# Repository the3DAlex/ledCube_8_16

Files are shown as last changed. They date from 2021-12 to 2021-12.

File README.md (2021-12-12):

# ledCube_8_16
When cube will be ready install https://github.com/LuisMiCa/IRsmallDecoder in Arduino IDE.
From Example>IRsmallDecoder open HelloNEC example.
In the "IRsmallDecoder irDecoder(2);"  put your port number (in our case 10)
In "Serial.begin(250000);" put your terminal speed (Arduino Serial Monitor default value is 9600)
Burn sketch to cube.
Get your IR Pult and press all button one by one and remember it cmd.
Open LEDCube8_16.ino  and in loop void ander switch statement put thous cmd numbers. 
For example : "case 0x13:" where 0x13 - is yor cmd = button.
Note that not all pult works with this library. If no cmd shown - try another pult.

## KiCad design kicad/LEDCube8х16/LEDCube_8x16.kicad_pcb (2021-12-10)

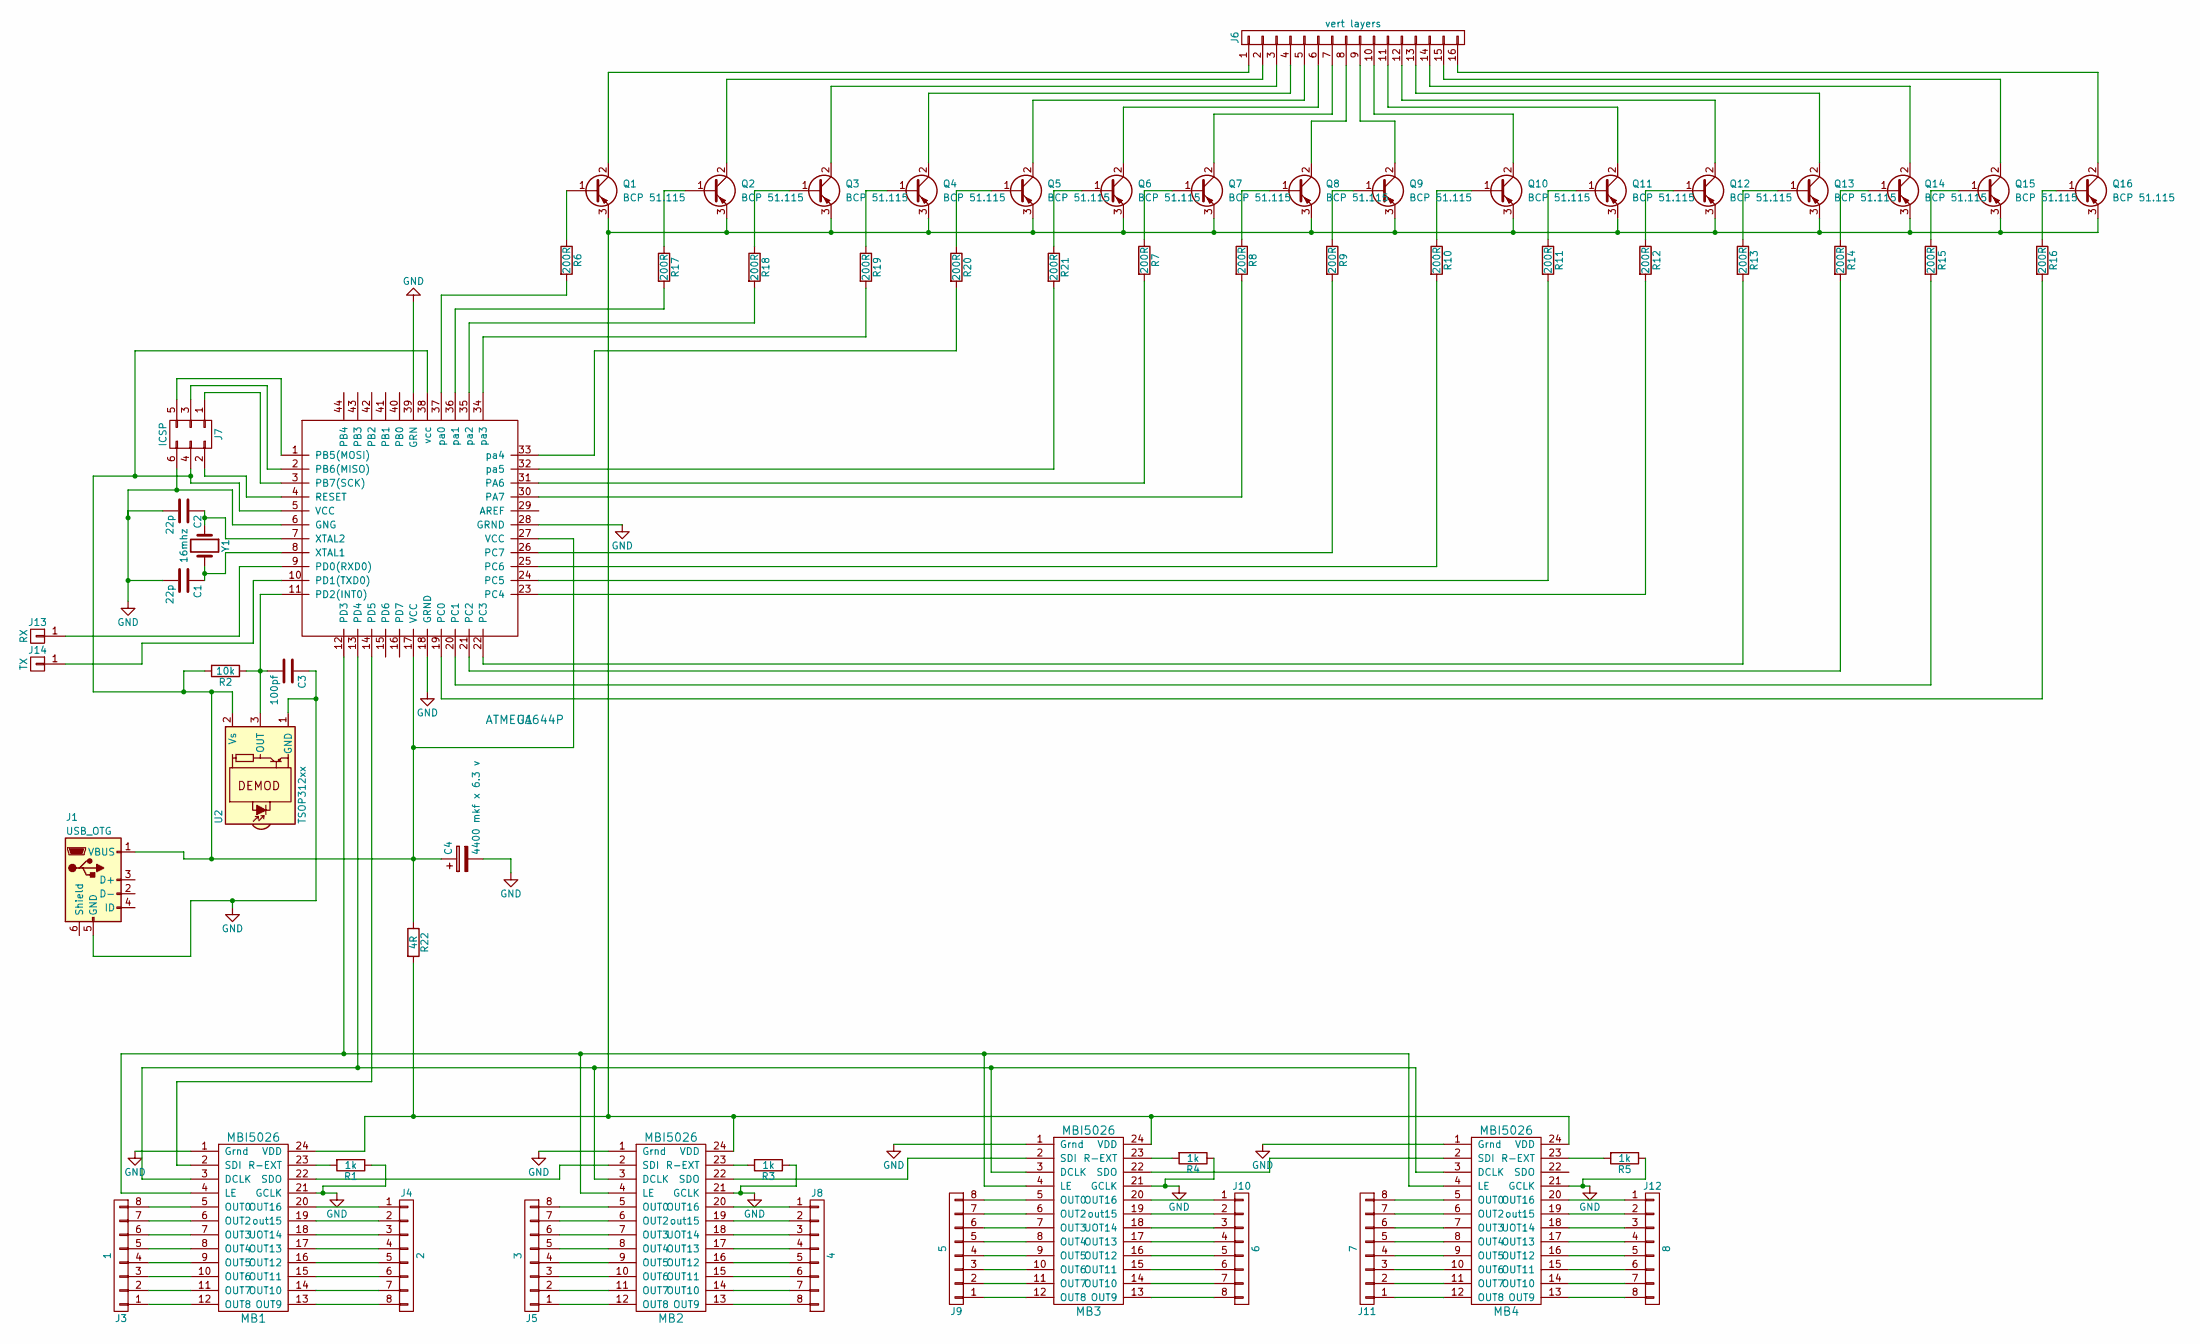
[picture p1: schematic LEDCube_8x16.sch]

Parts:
C1, C2: 22p; C_0805
C3: 100pf; C_0805
C4: 4400 mkf x 6.3 v; CP_Radial_D18.0mm_P7.50mm
J1: USB_OTG; USB_Micro-B
J3: 1; Pin_Header_Straight_1x08_Pitch1.00mm
J4: 2; Pin_Header_Straight_1x08_Pitch1.00mm
J5: 3; Pin_Header_Straight_1x08_Pitch1.00mm
J6: vert layers; Pin_Header_Straight_1x16_Pitch1.00mm
J7: ICSP; Pin_Header_Straight_2x03_Pitch2.54mm
J8: 4; Pin_Header_Straight_1x08_Pitch1.00mm
J9: 5; Pin_Header_Straight_1x08_Pitch1.00mm
J10: 6; Pin_Header_Straight_1x08_Pitch1.00mm
J11: 7; Pin_Header_Straight_1x08_Pitch1.00mm
J12: 8; Pin_Header_Straight_1x08_Pitch1.00mm
J13: RX; Pin_Header_Straight_1x01_Pitch2.54mm
J14: TX; Pin_Header_Straight_1x01_Pitch2.54mm
MB1, MB2, MB3, MB4: MBI5026; MBI5030
Q1, Q2, Q3, Q4, Q5, Q6, Q7, Q8, Q9, Q10, Q11, Q12, Q13, Q14, Q15, Q16: BCP 51.115; TO-92_Molded_Wide
R1, R3, R4, R5: 1k; R_0805
R2: 10k; R_0805
R6, R7, R8, R9, R10, R11, R12, R13, R14, R15, R16, R17, R18, R19, R20, R21: 200R; R_0805
R22: 4R; R_Axial_DIN0411_L9.9mm_D3.6mm_P7.62mm_Vertical
U1: ATMEGA644P; TQFP-44_10x10mm_Pitch0.8mm
U2: TSOP312xx; IRReceiver_Vishay_CAST-3pin
Y1: 16mhz; Crystal_HC49-U_Vertical

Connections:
GND: C1.2, C2.2, C3.1, C4.2, J1.5 (GND), J7.6, MB1.1 (Grnd), MB1.21 (GCLK), MB2.1 (Grnd), MB2.21 (GCLK), MB3.1 (Grnd), MB3.21 (GCLK), MB4.1 (Grnd), MB4.21 (GCLK), R1.1, R3.1, R4.1, R5.1, U1.6 (GNG), U1.18 (GRND), U1.28 (GRND), U1.39 (GRN), U2.1 (GND)
unnamed: C1.1, U1.8 (XTAL1), Y1.2
unnamed: C2.1, U1.7 (XTAL2), Y1.1
unnamed: C3.2, R2.1, U1.11 (PD2(INT0)), U2.3 (OUT)
unnamed: C4.1, J1.1 (VBUS), J7.4, R2.2, R22.1, U1.5 (VCC), U1.17 (VCC), U1.27 (VCC), U1.38 (vcc), U2.2 (Vs)
unnamed: J3.1, MB1.12 (OUT8)
unnamed: J3.2, MB1.11 (OUT7)
unnamed: J3.3, MB1.10 (OUT6)
unnamed: J3.4, MB1.9 (OUT5)
unnamed: J3.5, MB1.8 (OUT4)
unnamed: J3.6, MB1.7 (OUT3)
unnamed: J3.7, MB1.6 (OUT2)
unnamed: J3.8, MB1.5 (OUT0)
unnamed: J4.1, MB1.20 (OUT16)
unnamed: J4.2, MB1.19 (out15)
unnamed: J4.3, MB1.18 (UOT14)
unnamed: J4.4, MB1.17 (OUT13)
unnamed: J4.5, MB1.16 (OUT12)
unnamed: J4.6, MB1.15 (OUT11)
unnamed: J4.7, MB1.14 (OUT10)
unnamed: J4.8, MB1.13 (OUT9)
unnamed: J5.1, MB2.12 (OUT8)
unnamed: J5.2, MB2.11 (OUT7)
unnamed: J5.3, MB2.10 (OUT6)
unnamed: J5.4, MB2.9 (OUT5)
unnamed: J5.5, MB2.8 (OUT4)
unnamed: J5.6, MB2.7 (OUT3)
unnamed: J5.7, MB2.6 (OUT2)
unnamed: J5.8, MB2.5 (OUT0)
unnamed: J6.1, Q1.2 (C)
unnamed: J6.2, Q2.2 (C)
unnamed: J6.3, Q3.2 (C)
unnamed: J6.4, Q4.2 (C)
unnamed: J6.5, Q5.2 (C)
unnamed: J6.6, Q6.2 (C)
unnamed: J6.7, Q7.2 (C)
unnamed: J6.8, Q8.2 (C)
unnamed: J6.9, Q9.2 (C)
unnamed: J6.10, Q10.2 (C)
unnamed: J6.11, Q11.2 (C)
unnamed: J6.12, Q12.2 (C)
unnamed: J6.13, Q13.2 (C)
unnamed: J6.14, Q14.2 (C)
unnamed: J6.15, Q15.2 (C)
unnamed: J6.16, Q16.2 (C)
unnamed: J7.1, U1.3 (PB7(SCK))
unnamed: J7.2, U1.4 (RESET)
unnamed: J7.3, U1.2 (PB6(MISO))
unnamed: J7.5, U1.1 (PB5(MOSI))
unnamed: J8.1, MB2.20 (OUT16)
unnamed: J8.2, MB2.19 (out15)
unnamed: J8.3, MB2.18 (UOT14)
unnamed: J8.4, MB2.17 (OUT13)
unnamed: J8.5, MB2.16 (OUT12)
unnamed: J8.6, MB2.15 (OUT11)
unnamed: J8.7, MB2.14 (OUT10)
unnamed: J8.8, MB2.13 (OUT9)
unnamed: J9.1, MB3.12 (OUT8)
unnamed: J9.2, MB3.11 (OUT7)
unnamed: J9.3, MB3.10 (OUT6)
unnamed: J9.4, MB3.9 (OUT5)
unnamed: J9.5, MB3.8 (OUT4)
unnamed: J9.6, MB3.7 (OUT3)
unnamed: J9.7, MB3.6 (OUT2)
unnamed: J9.8, MB3.5 (OUT0)
unnamed: J10.1, MB3.20 (OUT16)
unnamed: J10.2, MB3.19 (out15)
unnamed: J10.3, MB3.18 (UOT14)
unnamed: J10.4, MB3.17 (OUT13)
unnamed: J10.5, MB3.16 (OUT12)
unnamed: J10.6, MB3.15 (OUT11)
unnamed: J10.7, MB3.14 (OUT10)
unnamed: J10.8, MB3.13 (OUT9)
unnamed: J11.1, MB4.12 (OUT8)
unnamed: J11.2, MB4.11 (OUT7)
unnamed: J11.3, MB4.10 (OUT6)
unnamed: J11.4, MB4.9 (OUT5)
unnamed: J11.5, MB4.8 (OUT4)
unnamed: J11.6, MB4.7 (OUT3)
unnamed: J11.7, MB4.6 (OUT2)
unnamed: J11.8, MB4.5 (OUT0)
unnamed: J12.1, MB4.20 (OUT16)
unnamed: J12.2, MB4.19 (out15)
unnamed: J12.3, MB4.18 (UOT14)
unnamed: J12.4, MB4.17 (OUT13)
unnamed: J12.5, MB4.16 (OUT12)
unnamed: J12.6, MB4.15 (OUT11)
unnamed: J12.7, MB4.14 (OUT10)
unnamed: J12.8, MB4.13 (OUT9)
unnamed: J13.1, U1.9 (PD0(RXD0))
unnamed: J14.1, U1.10 (PD1(TXD0))
unnamed: MB1.2 (SDI), U1.14 (PD5)
unnamed: MB1.3 (DCLK), MB2.3 (DCLK), MB3.3 (DCLK), MB4.3 (DCLK), U1.13 (PD4)
unnamed: MB1.4 (LE), MB2.4 (LE), MB3.4 (LE), MB4.4 (LE), U1.12 (PD3)
unnamed: MB1.22 (SDO), MB2.2 (SDI)
unnamed: MB1.23 (R-EXT), R1.2
unnamed: MB1.24 (VDD), MB2.24 (VDD), MB3.24 (VDD), MB4.24 (VDD), Q1.3 (E), Q2.3 (E), Q3.3 (E), Q4.3 (E), Q5.3 (E), Q6.3 (E), Q7.3 (E), Q8.3 (E), Q9.3 (E), Q10.3 (E), Q11.3 (E), Q12.3 (E), Q13.3 (E), Q14.3 (E), Q15.3 (E), Q16.3 (E), R22.2
unnamed: MB2.22 (SDO), MB3.2 (SDI)
unnamed: MB2.23 (R-EXT), R3.2
unnamed: MB3.22 (SDO), MB4.2 (SDI)
unnamed: MB3.23 (R-EXT), R4.2
unnamed: MB4.23 (R-EXT), R5.2
unnamed: Q1.1 (B), R6.1
unnamed: Q2.1 (B), R17.1
unnamed: Q3.1 (B), R18.1
unnamed: Q4.1 (B), R19.1
unnamed: Q5.1 (B), R20.1
unnamed: Q6.1 (B), R21.1
unnamed: Q7.1 (B), R7.1
unnamed: Q8.1 (B), R8.1
unnamed: Q9.1 (B), R9.1
unnamed: Q10.1 (B), R10.1
unnamed: Q11.1 (B), R11.1
unnamed: Q12.1 (B), R12.1
unnamed: Q13.1 (B), R13.1
unnamed: Q14.1 (B), R14.1
unnamed: Q15.1 (B), R15.1
unnamed: Q16.1 (B), R16.1
unnamed: R6.2, U1.37 (pa0)
unnamed: R7.2, U1.31 (PA6)
unnamed: R8.2, U1.30 (PA7)
unnamed: R9.2, U1.26 (PC7)
unnamed: R10.2, U1.25 (PC6)
unnamed: R11.2, U1.24 (PC5)
unnamed: R12.2, U1.23 (PC4)
unnamed: R13.2, U1.22 (PC3)
unnamed: R14.2, U1.21 (PC2)
unnamed: R15.2, U1.20 (PC1)
unnamed: R16.2, U1.19 (PC0)
unnamed: R17.2, U1.36 (pa1)
unnamed: R18.2, U1.35 (pa2)
unnamed: R19.2, U1.34 (pa3)
unnamed: R20.2, U1.33 (pa4)
unnamed: R21.2, U1.32 (pa5)

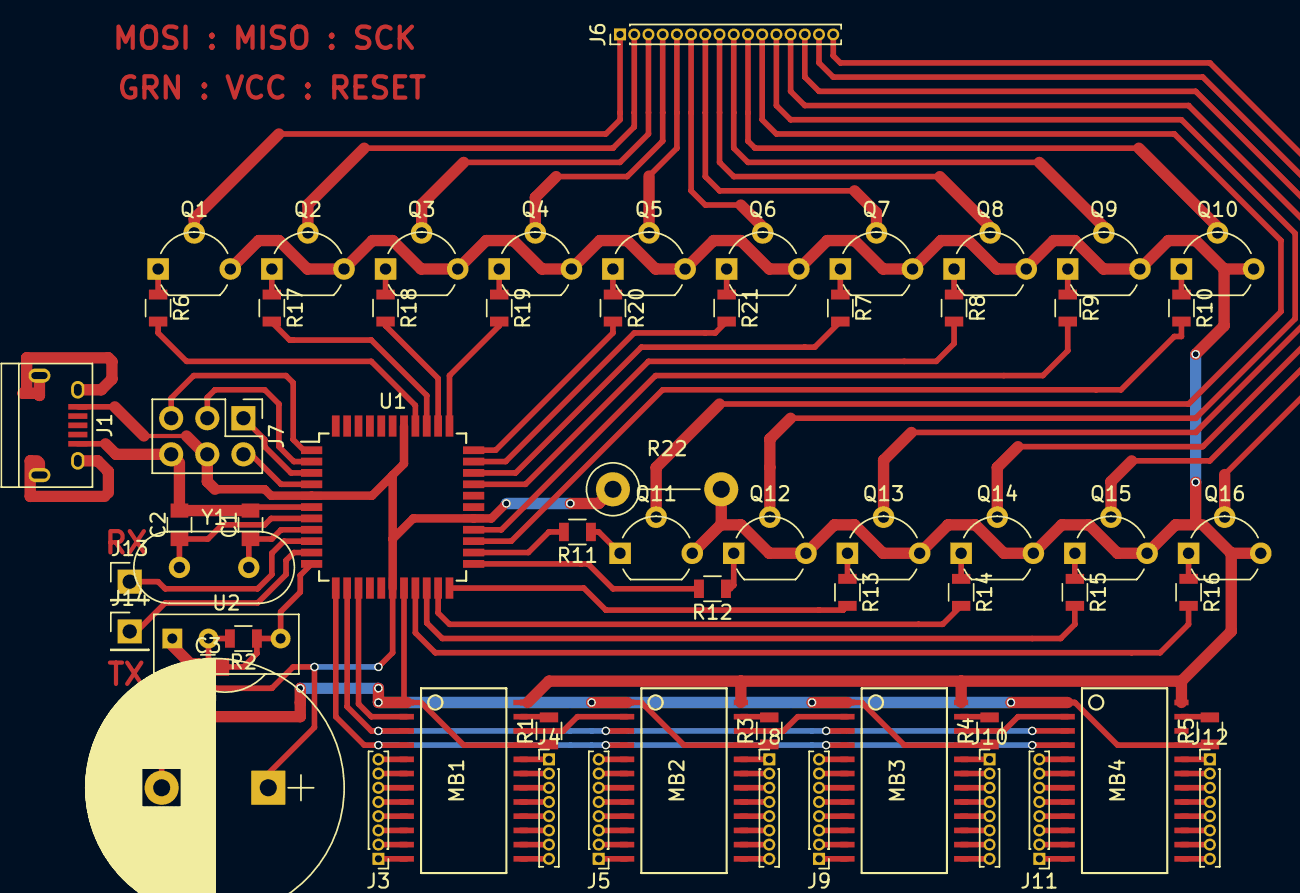
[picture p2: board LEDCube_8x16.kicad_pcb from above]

Board: 2 copper layers, 62 parts (0 on the bottom side), 134 nets.

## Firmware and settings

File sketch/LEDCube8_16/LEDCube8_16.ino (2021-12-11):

#define IR_SMALLD_NEC
#include <IRsmallDecoder.h> 

#define ISDEBUG false

#define DATA PD5
#define CLK  PD4
#define LE   PD3

#define SIZEx 8
#define SIZEy 8
#define SIZEz 16
#define SIZExLIM SIZEx - 1
#define SIZEyLIM SIZEy - 1
#define SIZEzLIM SIZEz - 1

#define TEXTTIME  1              // in seconds
#define timeToAutoChangeMode 10 // in seconds

IRsmallDecoder irDecoder(10);
irSmallD_t irData;

byte matrix[8][8][16];

uint8_t zCount = 0;
uint8_t mode = 1; // 0 - leds off; etc
uint8_t modesCount = 9;
uint8_t saluteCadr = 0;
uint8_t saluteX ,saluteY = 4;

unsigned long curTimeToAutoChangeMode = 0;
unsigned long showTextCounter = 0;
 
uint16_t counter = 0;

int xPos,yPos,zPos = 0;
int xSign = 1;
int ySign = 1;
int zSign = 1;



bool cyclingMode = false;
bool oneTime, textShowOnetime = true;

//=========================================================
void fillMatrix(byte val = 0)
{
   for(uint8_t z = 0; z < SIZEz; z ++)
   {
      for (uint8_t y = 0; y < SIZEy; y ++)
      {
          for (uint8_t x = 0; x < SIZEx; x ++)
          {
            matrix[x][y][z]=val;
          }
      }
   }
}

//=========================================================
void turnLayer(uint8_t layer)
{
  // LOW value at tranzistors base = opened = layer on
  if (layer < 8)
  {
    PORTA &= ~(1 << layer);
  }
  else
  {
    PORTC &= ~(1 << (15 - layer));
  }
}

//=========================================================
void turnOffLayers()
{
    // Hi value at tranzistors base = closed = layer off
    PORTA = 255; 
    PORTC = 255;
}
//==============================================================================
void sentData()
{
    turnOffLayers();          // turn off all tranzistors
    for (uint8_t y = 0; y < SIZEy; y ++)
    {
        for (uint8_t x = 0; x < SIZEx; x ++)
        {
           PORTD &= ~(1 << DATA);
           PORTD |= (matrix[x][y][zCount] << DATA);
           PORTD |= 1 << CLK;     //set clock pin to 1
           PORTD &= ~(1 << CLK);  //set clock pin to 0
        }
    }
    PORTD |= (1 << LE);       //turn on Latch
    turnLayer(zCount);           //turn on tranzistor = vertical layer
    PORTD &= ~(1 << LE); //turn off Latch
    zCount ++;
    if (zCount >= SIZEz)zCount = 0;
}

//==============================================================================
ISR(TIMER2_COMPA_vect)
{
    sentData();
}

//==============================================================================
void setPixel(uint8_t x, uint8_t y, uint8_t z, uint8_t val = 1)
{
  if (x >= 0 && x < SIZEx && y >= 0 && y < SIZEy && z >= 0 && z < SIZEz)   matrix[x][y][z] = val;
}

//==============================================================================
void sendTextToMatrix (byte indx[][2], uint8_t sizeOfArr)
{
    for (uint8_t x = 0; x < sizeOfArr; x ++) { setPixel(indx[x][0], 0, indx[x][1]); }
}
//////=========================================================
void drawText(uint8_t n)
{
   fillMatrix(0);
   switch (n)
    {
        case 0:
        {
          byte indx[][2] ={{2, 3},{3, 3},{4, 3},{5, 3},{1, 4},{6, 4},{1, 5},{6, 5},{1, 6},{6, 6},{1, 7},{6, 7},{1, 8},{6, 8},{1, 9},{6, 9},{1, 10},{6, 10},{1, 11},{6, 11},{2, 12},{3, 12},{4, 12},{5, 12}};
          sendTextToMatrix(indx, 24);
        }
        break; 
        case 1:
        {
          byte indx[][2] ={{3, 3},{3, 4},{3, 5},{3, 6},{3, 7},{3, 8},{3, 9},{3, 10},{5, 10},{3, 11},{4, 11},{3, 12}};
          sendTextToMatrix(indx, 12);
        }
        break;
        case 2:
        {
          byte indx[][2] ={{1, 3},{2, 3},{3, 3},{4, 3},{5, 3},{6, 3},{5, 4},{4, 5},{3, 6},{2, 7},{1, 8},{1, 9},{1, 10},{6, 10},{1, 11},{6, 11},{2, 12},{3, 12},{4, 12},{5, 12}};
          sendTextToMatrix(indx, 20);
        }
        break;
        case 3:
        {
          byte indx[][2] ={{2, 3},{3, 3},{4, 3},{5, 3},{1, 4},{6, 4},{1, 5},{6, 5},{1, 6},{1, 7},{2, 8},{3, 8},{4, 8},{1, 9},{1, 10},{6, 10},{1, 11},{6, 11},{2, 12},{3, 12},{4, 12},{5, 12}};
          sendTextToMatrix(indx, 22);
        }
        break;
        case 4:
        {
          byte indx[][2] ={{2, 3},{2, 4},{1, 5},{2, 5},{3, 5},{4, 5},{5, 5},{6, 5},{7, 5},{2, 6},{7, 6},{2, 7},{6, 7},{2, 8},{5, 8},{2, 9},{5, 9},{2, 10},{4, 10},{2, 11},{3, 11},{2, 12}};
          sendTextToMatrix(indx, 22);
        }
        break;
        case 5:
        {
          byte indx[][2] ={{2, 3},{3, 3},{4, 3},{5, 3},{2, 4},{6, 4},{1, 5},{6, 5},{1, 6},{1, 7},{1, 8},{6, 8},{2, 9},{3, 9},{4, 9},{5, 9},{6, 9},{6, 10},{5, 11},{1, 12},{2, 12},{3, 12},{4, 12},{5, 12}};
          sendTextToMatrix(indx, 24);
        }
        break;
        case 6:
        {
          byte indx[][2] ={{2, 3},{3, 3},{4, 3},{5, 3},{1, 4},{6, 4},{1, 5},{6, 5},{1, 6},{6, 6},{1, 7},{5, 7},{6, 7},{2, 8},{3, 8},{4, 8},{6, 8},{6, 9},{6, 10},{1, 11},{5, 11},{2, 12},{3, 12},{4, 12}};
          sendTextToMatrix(indx, 24);
        }
        break;
        case 7:
        {
          byte indx[][2] ={{4, 3},{4, 4},{4, 5},{3, 6},{3, 7},{3, 8},{2, 9},{2, 10},{1, 11},{1, 12},{2, 12},{3, 12},{4, 12},{5, 12},{6, 12}};
          sendTextToMatrix(indx, 15);
        }
        break;
        case 8:
        {
          byte indx[][2] ={{2, 3},{3, 3},{4, 3},{5, 3},{1, 4},{6, 4},{1, 5},{6, 5},{1, 6},{6, 6},{1, 7},{6, 7},{2, 8},{3, 8},{4, 8},{5, 8},{1, 9},{6, 9},{1, 10},{6, 10},{1, 11},{6, 11},{2, 12},{3, 12},{4, 12},{5, 12}};
          sendTextToMatrix(indx, 26);
        }
        break;
        case 9:
        {
          byte indx[][2] ={{3, 3},{4, 3},{5, 3},{2, 4},{6, 4},{1, 5},{1, 6},{1, 7},{3, 7},{4, 7},{5, 7},{1, 8},{2, 8},{6, 8},{1, 9},{6, 9},{1, 10},{6, 10},{1, 11},{6, 11},{2, 12},{3, 12},{4, 12},{5, 12}};
          sendTextToMatrix(indx, 24);
        }
        break;
    }
}

//==============================================================================
void rain()
{
   if (counter > 100) // counter for delay simulation
      {
          for(int8_t z = 0; z < SIZEzLIM; z ++)
          {
              for (int8_t x = 0; x < SIZEx; x ++)
              {
                  for (int8_t y = 0; y < SIZEy; y ++)
                  {
                      matrix[x][y][z] = matrix[x][y][z + 1];
                      matrix[x][y][z + 1] = 0;
                  }
              }
          }
          // spawn 3 new dot at top
          setPixel(random(0, SIZEx), random(0, SIZEy), SIZEzLIM);
          setPixel(random(0, SIZEx), random(0, SIZEy), SIZEzLIM);
          setPixel(random(0, SIZEx), random(0, SIZEy), SIZEzLIM);
          counter=0;
      }else
      {
        counter++;
      }
}

//==============================================================================
void rainWithCenter()
{
   if (counter > 100) // counter for delay simulation
      {
          // process center -----------------------------
          for(int8_t z = 0; z < SIZEzLIM; z ++)
          {
              for (int8_t x = 2; x < SIZEx - 2; x ++)
              {
                  for (int8_t y = 2; y < SIZEy - 2; y ++)
                  {
                      matrix[x][y][z] = matrix[x][y][z + 1];
                      matrix[x][y][z + 1] = 0;
                  }
              }
          }
          // spawn 3 new dot at top
          for (uint8_t i = 0; i < 3; i++)  setPixel(random(2, SIZEx - 2), random(2, SIZEy - 2), SIZEzLIM);

          // process borders -----------------------------
          for(int8_t z = SIZEzLIM; z > 0; z --)
          {
              for (int8_t x = 0; x < SIZEx ; x ++)
              {
                  for (int8_t y = 0; y < SIZEy ; y ++)
                  {
                      if (x < 2 || x > SIZExLIM - 2 || y < 2 || y > SIZEyLIM - 2)
                      {
                          matrix[x][y][z] = matrix[x][y][z - 1];
                          matrix[x][y][z - 1] = 0;
                      }
                  }
              }
          }
          // spawn 3 new dot at top
          setPixel(random(SIZEx - 2, SIZEx), random(0, SIZEy), 0);
          setPixel(random(0, 2), random(0, SIZEy), 0);
          setPixel(random(0, SIZEx), random(0, 2), 0);
          setPixel(random(0, SIZEx), random(SIZEy - 2, SIZEy), 0);

          counter=0;
      }else
      {
        counter++;
      }
}

//==============================================================================
void rainWithCenterInverted()
{
   if (counter > 100) // counter for delay simulation
      {
          // process center -----------------------------
          for(int8_t z = SIZEzLIM; z > 0; z --)
          {
              for (int8_t x = 2; x < SIZEx - 2; x ++)
              {
                  for (int8_t y = 2; y < SIZEy - 2; y ++)
                  {
                      matrix[x][y][z] = matrix[x][y][z - 1];
                      matrix[x][y][z - 1] = 0;
                  }
              }
          }
          // spawn 3 new dot at top
          for (uint8_t i = 0; i < 3; i++)  setPixel(random(2, SIZEx - 2), random(2, SIZEy - 2), 0);

          // process borders -----------------------------
          
          for(int8_t z = 0; z < SIZEzLIM; z ++)
          {
              for (int8_t x = 0; x < SIZEx ; x ++)
              {
                  for (int8_t y = 0; y < SIZEy ; y ++)
                  {
                      if (x < 2 || x > SIZExLIM - 2 || y < 2 || y > SIZEyLIM - 2)
                      {
                          matrix[x][y][z] = matrix[x][y][z + 1];
                          matrix[x][y][z + 1] = 0;
                      }
                  }
              }
          }
          // spawn 3 new dot at top
          setPixel(random(SIZEx - 2, SIZEx), random(0, SIZEy), SIZEzLIM);
          setPixel(random(0, 2), random(0, SIZEy), SIZEzLIM);
          setPixel(random(0, SIZEx), random(0, 2), SIZEzLIM);
          setPixel(random(0, SIZEx), random(SIZEy - 2, SIZEy), SIZEzLIM);

          counter=0;
      }else
      {
        counter++;
      }
}


//==============================================================================
void uppRain()
{
   if (counter > 100) // counter for delay simulation
      {
          for(int8_t z = SIZEzLIM; z > 0; z --)
          {
              for (int8_t x = 0; x < SIZEx; x ++)
              {
                  for (int8_t y = 0; y < SIZEy; y ++)
                  {
                      matrix[x][y][z] = matrix[x][y][z - 1];
                      matrix[x][y][z - 1] = 0;
                  }
              }
          }
          // spawn 3 new dot at top
          setPixel(random(0, SIZEx), random(0, SIZEy), 0);
          setPixel(random(0, SIZEx), random(0, SIZEy), 0);
          setPixel(random(0, SIZEx), random(0, SIZEy), 0);
          counter=0;
      }else
      {
        counter++;
      }
}
//==============================================================================
void stars()
{
  if (counter > 100)// counter for delay simulation
  {
      fillMatrix(0);
      for (uint8_t i = 0; i < 20; i++) //20 stars 
      {
         setPixel(random(0, SIZEx), random(0, SIZEy), random(0, SIZEz));
      }
      counter = 0;
  }else  counter ++;
}

//==============================================================================
void starsInv()
{
  if (counter > 100)// counter for delay simulation
  {
      fillMatrix(1);
      for (uint8_t i = 0; i < 20; i++) //20 stars 
      {
         setPixel(random(0, SIZEx), random(0, SIZEy), random(0, SIZEz), 0);
      }
      counter = 0;
  }else  counter ++;
}

//==============================================================================
void movingDot()
{
   if (oneTime)
   {
        xPos=random(2, SIZEx);
        yPos=random(2, SIZEy);
        zPos=random(2, SIZEz);
        setPixel(xPos, yPos, zPos);
        oneTime = false;
    }
    if (counter > 80)
    {
      counter = 0;
      xPos += xSign;
      yPos += ySign;
      zPos += zSign;
      uint8_t val1 = random(1, 3);
      uint8_t val2 = random(1, 3);
      uint8_t val3 = random(1, 3);
      if (xPos > SIZExLIM){xSign = -val1 * (xSign / abs(xSign)); xPos = SIZExLIM;}
      if (xPos < 1){xSign = -val1 * (xSign/abs(xSign)); xPos = 0;}
      if (yPos > SIZEyLIM){ySign = -val2 * (ySign/abs(ySign)); yPos = SIZEyLIM;}
      if (yPos < 1){ySign = -val2 * (ySign/abs(ySign)); yPos = 0;}
      if (zPos > SIZEzLIM){zSign = -val3 * (zSign/abs(zSign)); zPos = SIZEzLIM;}
      if (zPos < 1){zSign = -val3 * (zSign/abs(zSign)); zPos = 0;}

      fillMatrix(0);
      setPixel(xPos, yPos, zPos);
    }
    else  counter++;
}



//==============================================================================
void drawSphere(uint8_t a, uint8_t b, uint8_t c, uint8_t r)
{
  for(uint8_t z = 0; z < SIZEz; z ++)
   {
      for (uint8_t y = 0; y < SIZEy; y ++)
      {
          for (uint8_t x = 0; x < SIZEx; x ++)
          {
            int xa = x - a;
            int yb = y - b;
            int zc = z - c;
            if (xa * xa + yb * yb + zc * zc == r * r)  setPixel(x, y, z);
          }
      }
   }
}
//==============================================================================
void salute()
{
      fillMatrix(0);
      if ( saluteCadr < 10) drawSphere(saluteX, saluteY, saluteCadr, 0); else if (saluteCadr < 20) drawSphere(saluteX, saluteY, 10, saluteCadr - 10);
      saluteCadr ++;
      if (saluteCadr > 30) 
      {
        saluteCadr = 0;
        saluteX = random(1 , SIZExLIM);
        saluteY = random(1 , SIZEyLIM);
      }
      delay(50);
}

//==============================================================================
void processMode() 
{
    switch (mode)
      {
        case 0:
          fillMatrix(0);
        break;
        case 1:
          fillMatrix(1);
        break;
        case 2:
          rain();
        break;
        case 3:
          stars();
        break;
        case 4:
          rainWithCenter();
        break;
        case 5:
          starsInv();
        break;
        case 6:
          uppRain();
        break;
        case 7:
          stars();
        break;
        case 8:
          rainWithCenterInverted();
        break;
      }
}

//==============================================================================
void setup() 
{
    fillMatrix(0);
    DDRD |= 1 << CLK | 1 << DATA | 1 << LE; //set pins drives led Drivers to OUTPUT
    DDRC = 255; // all pins C port is OUTPUT (8 layers tranzistors)
    DDRA = 255; // all pins A port is OUTPUT (8 layers tranzistors)
    turnOffLayers(); 
    
    if (ISDEBUG)
    { 
      Serial.begin(9600); // start serial for debugging purpose
    }

    // Timer1 for background sending info to drivers
    cli(); 
    TCCR2A = 0; 
    TCCR2B = 0;    
    TCCR2B |= (1 << CS20) | (1 << CS21); // set clock devider to 32 . If this value will be lower - no time left for main code.
    TIMSK2 |= (1 << OCIE2A); //Set overflow channel A interrupt
    sei();
}

//==============================================================================
void loop() 
{
    if(irDecoder.dataAvailable(irData)) 
    { 
      bool rightButtonPressed = false;
      oneTime = true;
      textShowOnetime = true;
      saluteCadr = 0;
      cyclingMode = false;
      
      switch (irData.cmd)
      {
        case 0:
          mode = mode == 0 ? 1: 0;
          rightButtonPressed = true;
        break;
        case 0x13:
          mode = 1;
          rightButtonPressed = true;
        break;
        case 0xB:
          mode = 2;
          rightButtonPressed = true;
        break;
        case 0x1B:
          mode = 3;
          rightButtonPressed = true;
        break;
        case 0x3:
          mode = 4;
          rightButtonPressed = true;
        break;
        case 0x14:
          mode = 5;
          rightButtonPressed = true;
        break;
        case 0xC:
          mode = 6;
          rightButtonPressed = true;
        break;
        case 0x1C:
          mode = 7;
          rightButtonPressed = true;
        break;
        case 0x4:
          mode = 8;
          rightButtonPressed = true;
        break;
        case 0x19:
          cyclingMode = true;
          curTimeToAutoChangeMode = millis();
          mode = 1;
        break;
      }
      if (rightButtonPressed) showTextCounter = millis(); //do not show text if not defined buttons pressed
    }
  
    if (millis() - showTextCounter < TEXTTIME * 1000)
    {
      if (textShowOnetime) 
      {
        drawText(mode);
        textShowOnetime = false;
      }
    }
    else
    {
        if (cyclingMode)
        {
            if(millis() - curTimeToAutoChangeMode > timeToAutoChangeMode * 1000)
            {
              curTimeToAutoChangeMode = millis();
              mode ++;
              if (mode >= modesCount) mode = 1;
            }
        }
        processMode();
    }
    delayMicroseconds(100);
}

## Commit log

2021-12-02 kicad files
    [LEDCube_8x16.kicad_pcb, LEDCube_8x16.sch]
2021-12-07 prefinished scetch
    [LEDCube_8x16-2021-12-02-20-27-40.sch]
2021-12-08 fixes in scheme
    [LEDCube_8x16.kicad_pcb, LEDCube_8x16.sch]
2021-12-08 added resistor between mcu and leds
    [LEDCube_8x16.kicad_pcb, LEDCube_8x16.sch]
